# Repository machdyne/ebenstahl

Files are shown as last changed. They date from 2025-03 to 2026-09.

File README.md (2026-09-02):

# Ebenstahl Storage Device

Ebenstahl is a desktop storage controller with sockets for up to 16 [MMOD](https://github.com/machdyne/mmod) modules. When paired with FRAM, EEPROM or SuperFlash MMODs, it can be used to build a low-cost long-term storage array.

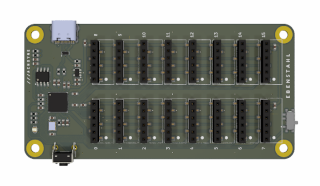
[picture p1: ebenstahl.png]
Ebenstahl


This repo contains schematics, USB-MSC firmware and a 3D-printable case.

Find more information on the [Ebenstahl product page](https://machdyne.com/product/ebenstahl-storage-device/).

Also see the [FERRIT](https://github.com/machdyne/ferrit) project for more storage.

**Note: The EEPROM and Flash drivers are experimental and wear-leveling is not supported.**

### Supported Boards

 * [Ebenstahl](https://machdyne.com/product/ebenstahl-storage-device/)
 * [Graustahl](https://machdyne.com/product/graustahl-storage-device/)
 * [Kaltstahl](https://machdyne.com/product/kaltstahl-storage-device/)
 * [Blaustahl](https://machdyne.com/product/blaustahl-storage-device/)

To use this firmware with Graustahl, Kaltstahl or Blaustahl you will need to set the appropriate board definition in ebenstahl.h. For Blaustahl will you also need to comment out FRAM\_BIG in drv\_fram.c.

In all cases you will need to configure the LUN mappings in mapper.c.

You can build the firmware from source, if you have [pico-sdk](https://github.com/raspberrypi/pico-sdk) installed:

```
$ cd firmware/ebenstahl
$ mkdir build
$ cd build
$ cmake .. && make
```

## License

The contents of this repo are released under the [Lone Dynamics Open License](LICENSE.md).

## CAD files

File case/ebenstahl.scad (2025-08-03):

/*
 * Ebenstahl Case
 * Copyright (c) 2025 Lone Dynamics Corporation. All rights reserved.
 *
 * required hardware:
 *  - 4 x M3 x 30mm countersunk bolts
 *  - 4 x M3 nuts
 *
 */

$fn = 100;

board_width = 50;
board_thickness = 1.5;
board_length = 100;
board_height = 1.6;
board_spacing = 2;

wall = 2;

top_height = 25;
bottom_height = 6;

translate([wall,wall,4]) ssz_board();

color([1,0,0]) translate([0,0,5])
    ssz_case_top();

color([1,0,0]) translate([0,0,0])
	ssz_case_bottom();

translate([0,0,15])
	ssz_case_slide();

module ssz_board() {
	
	difference() {
		color([0,0.5,0])
			roundedcube(board_width,board_length,board_thickness,4);
		translate([4, 4, -1]) cylinder(d=3.2, h=10);
		translate([4, 100-4, -1]) cylinder(d=3.2, h=10);
		translate([50-4, 4, -1]) cylinder(d=3.2, h=10);
		translate([50-4, 100-4, -1]) cylinder(d=3.2, h=10);
	}	
	
}

module ssz_case_top() {

	translate([54,75,19])
		rotate([90,0,90])
			translate([0,-10,0])
				linear_extrude(1)
					text("EBENSTAHL", size=5, halign="center",
						font="Lato Black");

	// supports
	translate([wall, wall, 0]) {
	}
	
	difference() {
				
		color([0.5,0.5,0.5])
			roundedcube(board_width+(wall*2),board_length+(wall*2),top_height,4);

		// cutouts
			
		translate([2,8.5,-2])
			roundedcube(board_width,board_length-13,25,5);

		translate([8.5,2,-2])
			roundedcube(board_width-13,board_length,25,5);			
	
		translate([wall, wall, 0]) {

			// vents
			//translate([(52/2)-5,-5,10]) rotate([0,0,90]) cube([15,1,20]);
			//translate([(52/2),-5,10]) rotate([0,0,90]) cube([15,1,20]);
			//translate([(52/2)+5,-5,10]) rotate([0,0,90]) cube([15,1,20]);
			
			// USBC
			translate([-10,15-(9.5/2),0]) cube([30,9.5,3.5]);

			// LED vent
   			translate([37.5,25,5]) rotate([90,0,0]) cylinder(d=1.5, h=100);
            translate([37.5,25,7.5]) rotate([90,0,0]) cylinder(d=1.5, h=100);
            translate([37.5,25,10]) rotate([90,0,0]) cylinder(d=1.5, h=100);

			// BOOTSEL
			translate([30,15-(8/2),-1]) cube([30,8,7.5+1]);

			// WP
			translate([50-14.2425-(9/2),99,-1]) cube([9,10,2.5+1]);
				
			// bolt holes
			translate([4, 4, -15]) cylinder(d=3.5, h=40);
			translate([4, 100-4, -15]) cylinder(d=3.5, h=40);
			translate([50-4, 4, -14]) cylinder(d=3.5, h=40);
			translate([50-4, 100-4, -14]) cylinder(d=3.5, h=40);

			// flush mount bolt holes
			translate([4, 4, top_height-1.75]) cylinder(d=6, h=4);
			translate([4, 100-4, top_height-1.75]) cylinder(d=6, h=4);
			translate([50-4, 4, top_height-1.75]) cylinder(d=6, h=4);
			translate([50-4, 100-4, top_height-1.75]) cylinder(d=6, h=4);


		}
		
	}	
}

module ssz_case_bottom() {
	
	difference() {
		color([0.5,0.5,0.5])
			roundedcube(board_width+(wall*2),board_length+(wall*2),bottom_height,4);
		
		// cutouts
		translate([3.5,10,1.5])
			roundedcube(board_width-3,board_length-17,10,5);
				
		translate([10.5,3,1.5])
			roundedcube(board_width-17.5,board_length-2,10,5);

		translate([wall, wall, 0]) {
			
		// board cutout
		translate([0,0,bottom_height-board_height])
			roundedcube(board_width+0.2,board_length+0.2,board_height+1,2.5);

		// USBC
		translate([0,17.275-(10/2),1.5]) cube([30,10,3.5]);

		// BOOTSEL
		translate([20.2,17.275-(10/2),1.5]) cube([30,10,7.5+1]);
            
		// bolt holes
		translate([4, 4, -11]) cylinder(d=3.2, h=25);
		translate([4, 100-4, -11]) cylinder(d=3.2, h=25);
		translate([50-4, 4, -11]) cylinder(d=3.2, h=25);
		translate([50-4, 100-4, -11]) cylinder(d=3.2, h=25);

		// nut holes
		translate([4, 4, -1]) cylinder(d=7, h=4, $fn=6);
		translate([4, 100-4, -1]) cylinder(d=7, h=4, $fn=6);
		translate([50-4, 4, -1]) cylinder(d=7, h=4, $fn=6);
		translate([50-4, 100-4, -1]) cylinder(d=7, h=4, $fn=6);

		}
		
	}	
}

// https://gist.github.com/tinkerology/ae257c5340a33ee2f149ff3ae97d9826
module roundedcube(xx, yy, height, radius)
{
    translate([0,0,height/2])
    hull()
    {
        translate([radius,radius,0])
        cylinder(height,radius,radius,true);

        translate([xx-radius,radius,0])
        cylinder(height,radius,radius,true);

        translate([xx-radius,yy-radius,0])
        cylinder(height,radius,radius,true);

        translate([radius,yy-radius,0])
        cylinder(height,radius,radius,true);
    }
}

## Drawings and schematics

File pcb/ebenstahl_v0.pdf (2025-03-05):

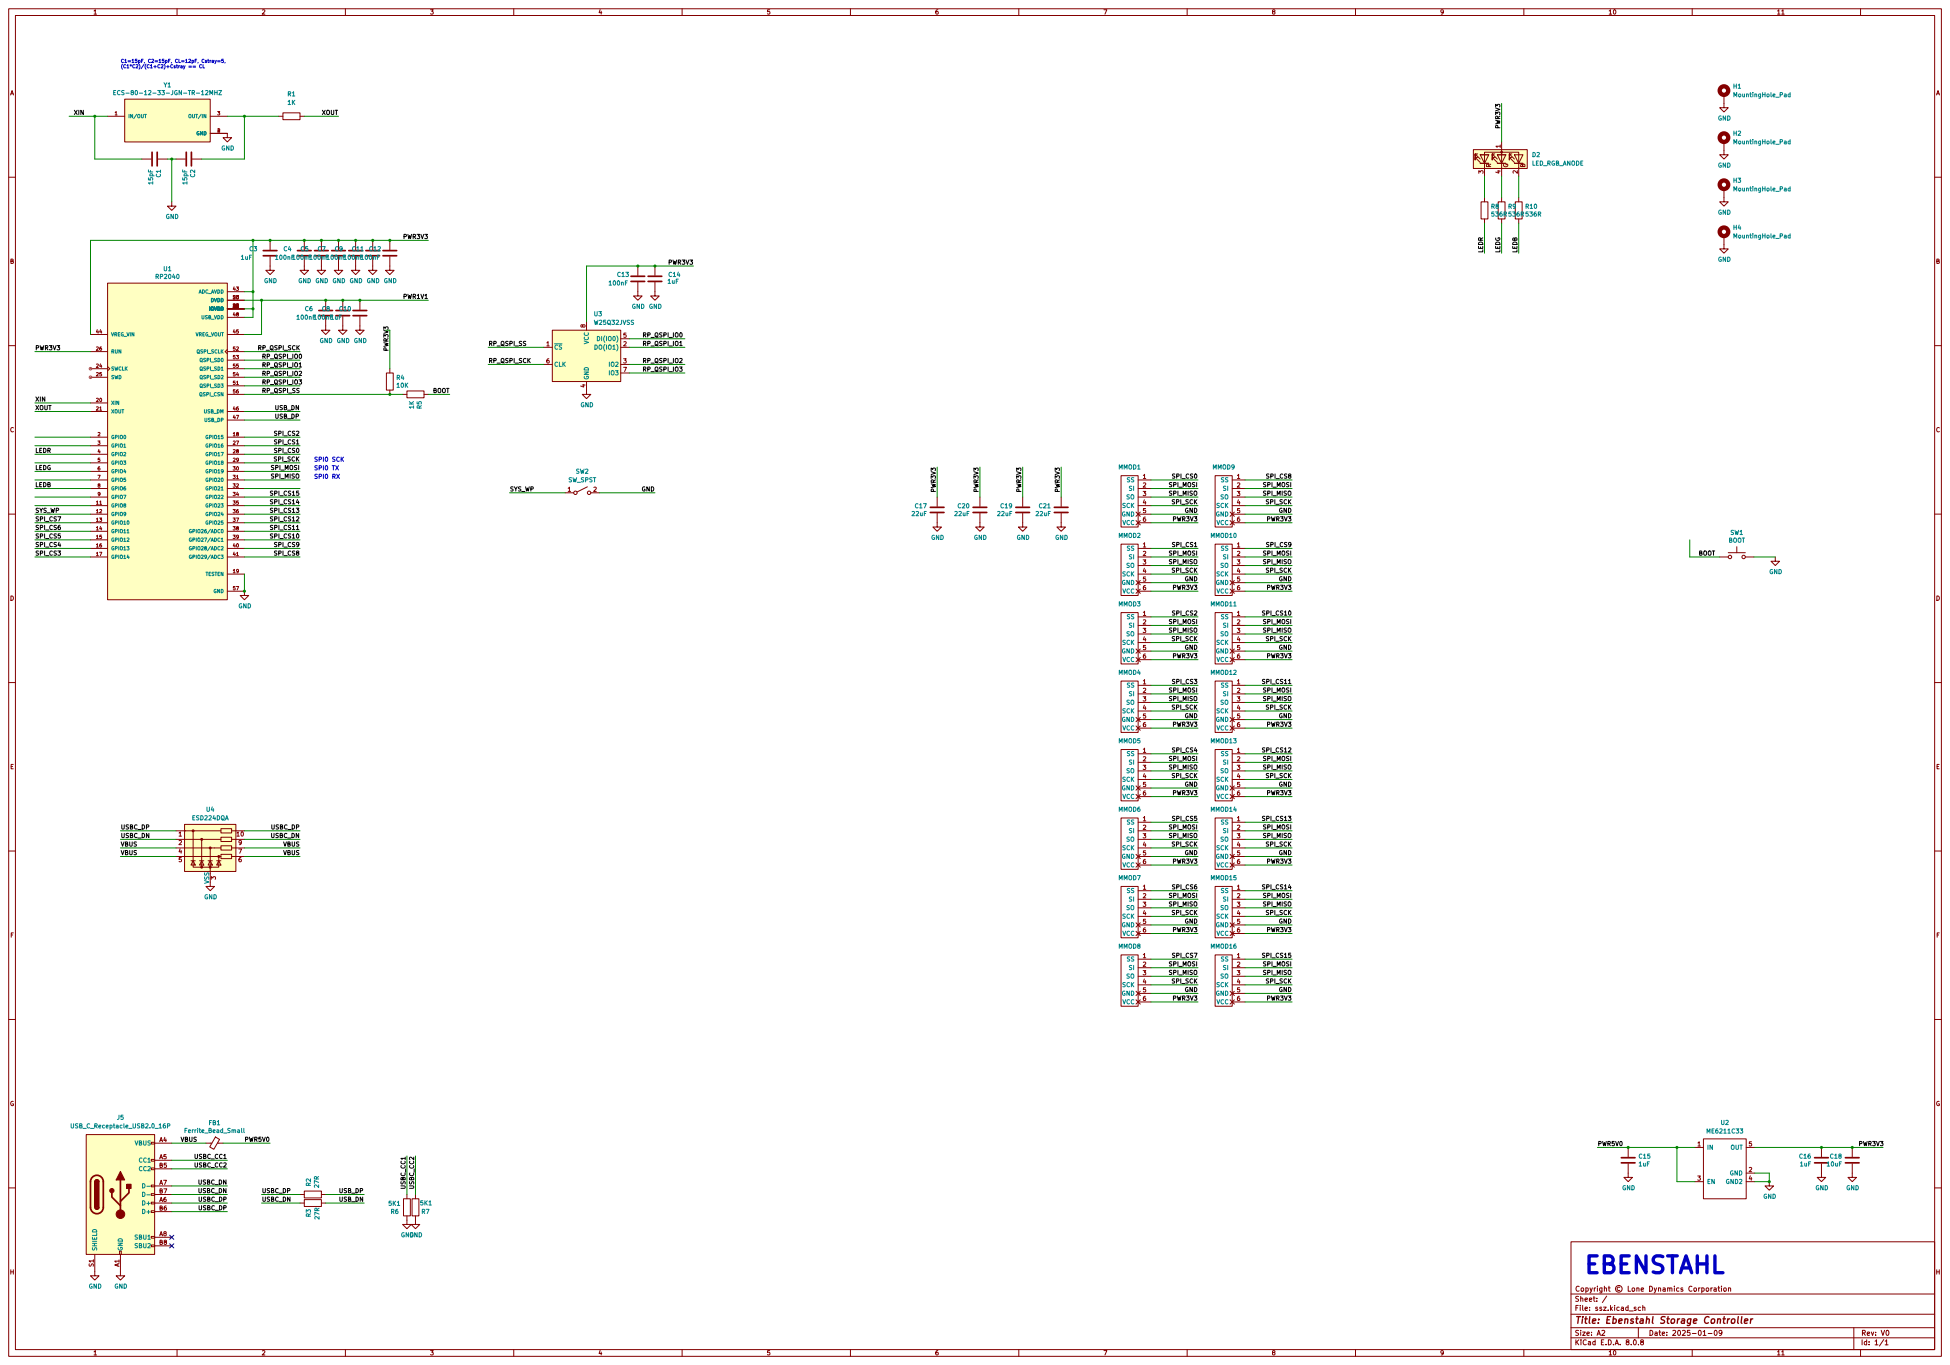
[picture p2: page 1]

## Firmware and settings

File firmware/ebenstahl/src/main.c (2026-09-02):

/*
 * The MIT License (MIT)
 *
 * Copyright (c) 2019 Ha Thach (tinyusb.org)
 * Copyright (c) 2025 Lone Dynamics Corporation
 *
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
 */

#include <stdlib.h>
#include <stdio.h>
#include <string.h>

#include "pico/stdlib.h"
#include "tusb.h"

#include "ebenstahl.h"
#include "usb_msc.h"
#include "led.h"
#include "drv_fram.h"
#include "drv_eeprom.h"
#include "drv_flash.h"

//--------------------------------------------------------------------+
// MACRO CONSTANT TYPEDEF PROTYPES
//--------------------------------------------------------------------+

/*------------- MAIN -------------*/
int main(void) {

	es_init();
	led_init();
	fram_init();
	eeprom_init();
	flash_init();

	// init device stack on configured roothub port
	tud_init(BOARD_TUD_RHPORT);

	while (1) {
		tud_task(); // tinyusb device task
		led_task();
	}

}

//--------------------------------------------------------------------+
// Device callbacks
//--------------------------------------------------------------------+

// Invoked when device is mounted
void tud_mount_cb(void) {
  // a fresh enumeration re-inserts the medium on every LUN, so that
  // replugging the device recovers from a host-initiated eject
  usb_msc_reset_eject();
  led_set_link(LED_LINK_MOUNTED);
}

// Invoked when device is unmounted
void tud_umount_cb(void) {
  led_set_link(LED_LINK_UNMOUNTED);
}

// Invoked when usb bus is suspended
// remote_wakeup_en : if host allow us  to perform remote wakeup
// Within 7ms, device must draw an average of current less than 2.5 mA from bus
void tud_suspend_cb(bool remote_wakeup_en) {
  (void) remote_wakeup_en;
  led_set_link(LED_LINK_SUSPENDED);
}

// Invoked when usb bus is resumed
void tud_resume_cb(void) {
  led_set_link(tud_mounted() ? LED_LINK_MOUNTED : LED_LINK_UNMOUNTED);
}

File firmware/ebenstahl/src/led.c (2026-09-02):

/*
 * Ebenstahl LED
 * Copyright (c) 2025 Lone Dynamics Corporation. All rights reserved.
 *
 * The LED reflects two independent pieces of state -- the USB link and the
 * SCSI medium -- plus two momentary overlays (activity and fault). led_task()
 * renders whichever of these has the highest priority:
 *
 *   1. fault      red flash            (rapid blink on single-LED boards)
 *   2. suspended  off
 *   3. unmounted  green blink
 *   4. ejected    steady blue          (short blink every 2s on single-LED)
 *   5. activity   green, full brightness
 *   6. idle       green, breathing
 *
 * Brightness is PWM'd for two reasons: the LEDs are bright enough to be
 * distracting at full duty, and the idle breathe needs a smooth ramp.
 */

#include <stdbool.h>

#include "pico/stdlib.h"
#include "hardware/pwm.h"

#include "ebenstahl.h"
#include "led.h"

// 1023 @ default clkdiv puts the carrier at ~122kHz, far above visible
// flicker, and 10 bits keeps resolution where it matters: the bottom of
// the curve, where a dimmed breathe spends most of its time.
#define LED_PWM_TOP				1023

/*
 * Per-channel brightness ceilings, in perceptual units (0-255).
 *
 * All three channels share a 536R resistor but the LED forward voltages
 * differ a lot: red is roughly (3.3-2.0)/536 = 2.4mA while green and blue
 * sit near 3.0V Vf and draw only ~0.6mA. Red is therefore about 4x the
 * current of the other two, and a single global cap would leave it glaring
 * while green stayed dim. These are estimates from the schematic, not
 * measured -- tune them against real hardware.
 */
#define LED_TRIM_R				70
#define LED_TRIM_G				160
#define LED_TRIM_B				180
#define LED_TRIM_MONO			160

#define LED_ACTIVITY_MS			40		// activity stretch, see led_note_activity()
#define LED_BREATHE_MS			4000	// full breathe cycle
#define LED_BREATHE_MIN			60		// idle floor; never fully extinguishes
#define LED_BREATHE_MAX			180		// stays well under the activity level, so a
										// breath peak can't be mistaken for a transfer
#define LED_BLINK_UNMOUNTED_MS	250
#define LED_EJECT_PERIOD_MS		2000
#define LED_EJECT_BLINK_MS		120

#ifdef ES_HAS_RGB_LED
#define LED_FAULT_MS			400		// single red flash
#else
#define LED_FAULT_MS			1000	// rapid blink burst
#define LED_FAULT_BLINK_MS		100
#endif

static led_link_t led_link = LED_LINK_UNMOUNTED;
static led_medium_t led_medium = LED_MEDIUM_PRESENT;

static bool led_activity_pending = false;
static uint32_t led_activity_ts = 0;

static bool led_fault_pending = false;
static uint32_t led_fault_ts = 0;

static uint32_t led_epoch = 0;

static inline uint32_t led_now_ms(void) {
	return to_ms_since_boot(get_absolute_time());
}

/*
 * Perceptual brightness (0-255) to PWM level.
 *
 * A linear duty ramp looks like it snaps bright early and then plateaus, so
 * the breathe needs gamma correction to look natural. b*b >> 6 is gamma 2.0
 * in integer arithmetic and tops out at 1016, just under LED_PWM_TOP.
 */
static inline uint16_t led_gamma(uint8_t b) {
	return (uint16_t)(((uint32_t)b * (uint32_t)b) >> 6);
}

static inline void led_put(uint gpio, uint8_t value, uint8_t trim) {
	uint8_t scaled = (uint8_t)(((uint32_t)value * (uint32_t)trim) / 255);
	pwm_set_gpio_level(gpio, led_gamma(scaled));
}

#ifdef ES_HAS_RGB_LED
static void led_rgb(uint8_t r, uint8_t g, uint8_t b) {
	led_put(ES_LEDR, r, LED_TRIM_R);
	led_put(ES_LEDG, g, LED_TRIM_G);
	led_put(ES_LEDB, b, LED_TRIM_B);
}
#else
static void led_mono(uint8_t v) {
	led_put(ES_LED, v, LED_TRIM_MONO);
}
#endif

static void led_pwm_init_pin(uint gpio) {

	gpio_set_function(gpio, GPIO_FUNC_PWM);

	uint slice = pwm_gpio_to_slice_num(gpio);
	uint chan = pwm_gpio_to_channel(gpio);

	pwm_set_wrap(slice, LED_PWM_TOP);

#if ES_LED_ACTIVE_LOW
	// the LEDs are common anode, so invert in hardware rather than writing
	// (TOP - level) at every call site
	pwm_set_output_polarity(slice, chan == PWM_CHAN_A, chan == PWM_CHAN_B);
#endif

	pwm_set_chan_level(slice, chan, 0);
	pwm_set_enabled(slice, true);

}

void led_init(void) {

#ifdef ES_HAS_RGB_LED
	// R, G and B land on separate PWM slices (GPIO n -> slice (n>>1)&7), so
	// each channel gets an independent duty with no shared-counter conflict
	led_pwm_init_pin(ES_LEDR);
	led_pwm_init_pin(ES_LEDG);
	led_pwm_init_pin(ES_LEDB);
	led_rgb(0, 0, 0);
#else
	led_pwm_init_pin(ES_LED);
	led_mono(0);
#endif

	led_epoch = led_now_ms();

}

void led_set_link(led_link_t link) {
	led_link = link;
}

void led_set_medium(led_medium_t medium) {
	led_medium = medium;
}

// A single 512-byte SPI transfer finishes in well under a millisecond, so
// bursts are stretched to LED_ACTIVITY_MS to make them visible. Sustained
// transfers hold the LED at full brightness.
void led_note_activity(void) {
	led_activity_ts = led_now_ms();
	led_activity_pending = true;
}

void led_note_fault(void) {
	led_fault_ts = led_now_ms();
	led_fault_pending = true;
}

// triangle ramp through the gamma curve, LED_BREATHE_MIN..LED_BREATHE_MAX
static uint8_t led_breathe_level(uint32_t now) {

	uint32_t phase = (uint32_t)(now - led_epoch) % LED_BREATHE_MS;
	uint32_t half = LED_BREATHE_MS / 2;

	uint32_t tri = (phase < half) ?
	    (phase * 255u / half) : ((LED_BREATHE_MS - phase) * 255u / half);

	if (tri > 255u) tri = 255u;

	return (uint8_t)(LED_BREATHE_MIN +
	    ((tri * (LED_BREATHE_MAX - LED_BREATHE_MIN)) / 255u));

}

void led_task(void) {

	uint32_t now = led_now_ms();

	// 1. fault
	if (led_fault_pending) {
		if ((uint32_t)(now - led_fault_ts) < LED_FAULT_MS) {
#ifdef ES_HAS_RGB_LED
			led_rgb(255, 0, 0);
#else
			bool on = (((uint32_t)(now - led_fault_ts) /
			    LED_FAULT_BLINK_MS) & 1u) == 0u;
			led_mono(on ? 255 : 0);
#endif
			return;
		}
		led_fault_pending = false;
	}

	// 2. suspended: USB requires < 2.5mA average from a bus-powered device
	// in suspend, so the LED goes dark rather than blinking
	if (led_link == LED_LINK_SUSPENDED) {
#ifdef ES_HAS_RGB_LED
		led_rgb(0, 0, 0);
#else
		led_mono(0);
#endif
		return;
	}

	// 3. waiting for enumeration
	if (led_link == LED_LINK_UNMOUNTED) {
		bool on = ((now / LED_BLINK_UNMOUNTED_MS) & 1u) != 0u;
#ifdef ES_HAS_RGB_LED
		led_rgb(0, on ? 200 : 0, 0);
#else
		led_mono(on ? 200 : 0);
#endif
		return;
	}

	// 4. medium ejected: steady, so it can't be mistaken for the idle breathe
	if (led_medium == LED_MEDIUM_EJECTED) {
#ifdef ES_HAS_RGB_LED
		led_rgb(0, 0, 200);
#else
		bool on = (now % LED_EJECT_PERIOD_MS) < LED_EJECT_BLINK_MS;
		led_mono(on ? 200 : 0);
#endif
		return;
	}

	// 5. activity
	if (led_activity_pending) {
		if ((uint32_t)(now - led_activity_ts) < LED_ACTIVITY_MS) {
#ifdef ES_HAS_RGB_LED
			led_rgb(0, 255, 0);
#else
			led_mono(255);
#endif
			return;
		}
		led_activity_pending = false;
	}

	// 6. mounted and idle
	uint8_t b = led_breathe_level(now);
#ifdef ES_HAS_RGB_LED
	led_rgb(0, b, 0);
#else
	led_mono(b);
#endif

}

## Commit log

2025-03-05 support other stahl devices
2025-03-05 init cs on non-ebenstahl devices
2025-08-03 graustahl support
    [ebenstahl.scad]
2026-08-24 fix boundary bug on multi-module boards; add experimental EEPROM and flash drivers
    [drv_eeprom.c, drv_flash.c, ebenstahl.c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]
2026-09-02 eject properly; led improvements
